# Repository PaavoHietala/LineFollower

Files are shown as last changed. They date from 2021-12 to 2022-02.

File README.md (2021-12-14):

# Line follower

Repository to build and program a line follower robot with arduino MEGA 2560.

The robot follows a line with two IR sensors and senses objects in front using ultrasound.

Course project for GCMG - Computational Graphics and Geometric Modelling of Técnico Lisboa.

## Arduino schematic

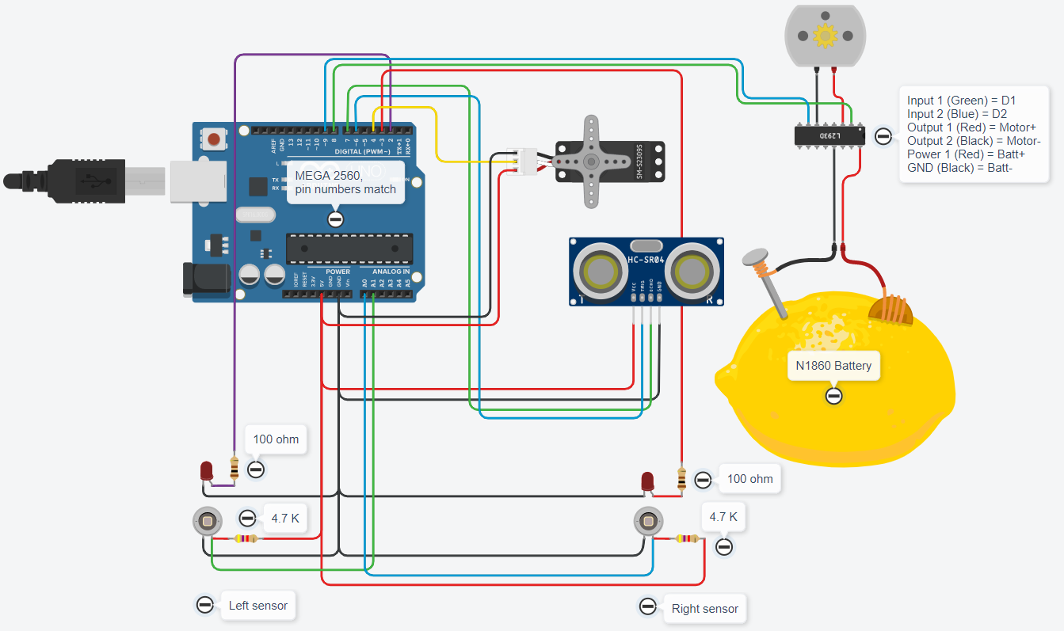
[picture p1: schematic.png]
Schematic Schematic, view PNG for increased resolution


Parts:
- 2 x TCRT5000 IR LED / photodiode combo
- Ultrasound sensor HC-SR04
- 2 x 100 ohm resistors
- 2 x 4.7 kohm resistors
- N18650 battery
- Small DC motor
- SG90 micro servo
- QUDONG BOSUN K-MEN motor controller (4-channel L9110)
- Whole lot of wire and soldering supplies

## Instructions

1. Build the electronics
2. Load the code to your arduino
3. Double check the pins in code and physical world

## Usage

The bot is autonomous. As long as it receives power, the program will run.

## Contributing

Unfortunately this project is my coursework, hence I am unable to receive external contributions. You can buy me a coffee if we meet though.

## License
[MIT](https://choosealicense.com/licenses/mit/)

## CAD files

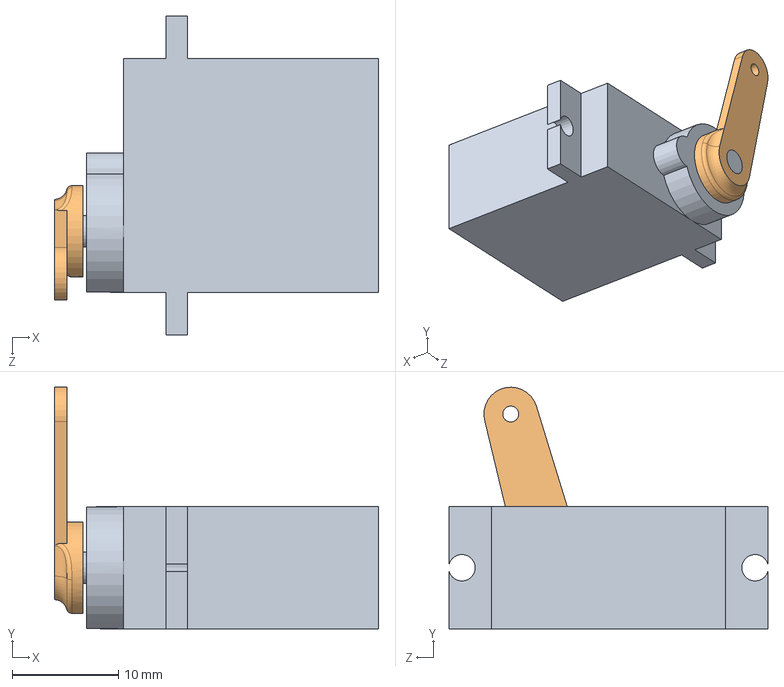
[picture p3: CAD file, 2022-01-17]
Solidworks/SG90 Servo Motor/servo assembly.SLDASM
30.5 x 22.7 x 30.0 mm
servo junk
servo junk 2

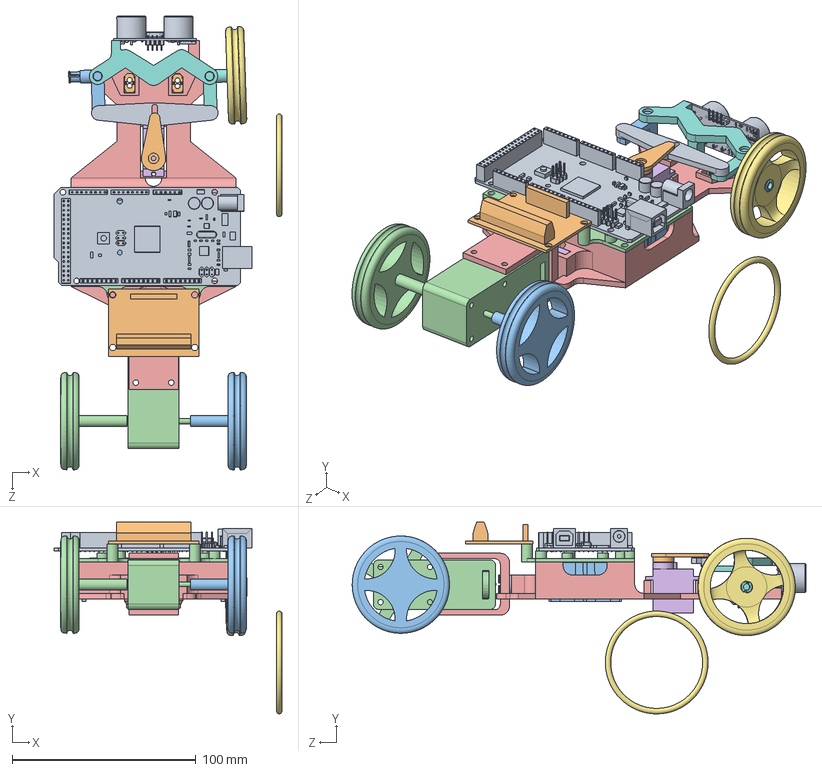
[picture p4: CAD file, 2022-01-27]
Solidworks/lineFollower.SLDASM
124.2 x 104.4 x 247.1 mm
Arduino Mega 2560
User Library-corpo TCRT 5000 x 2
Batt_Pack_Main
chassis_battery_cover
chassis_lower
servo junk
wheel
front_axle
steering_axle
servo_arm
front_axle_left_mirror
motor
motor_holder
motor_hinge
o-ring
front_fender
hc-sr04
motor_control_board
wheel_back_right
wheel_back_left

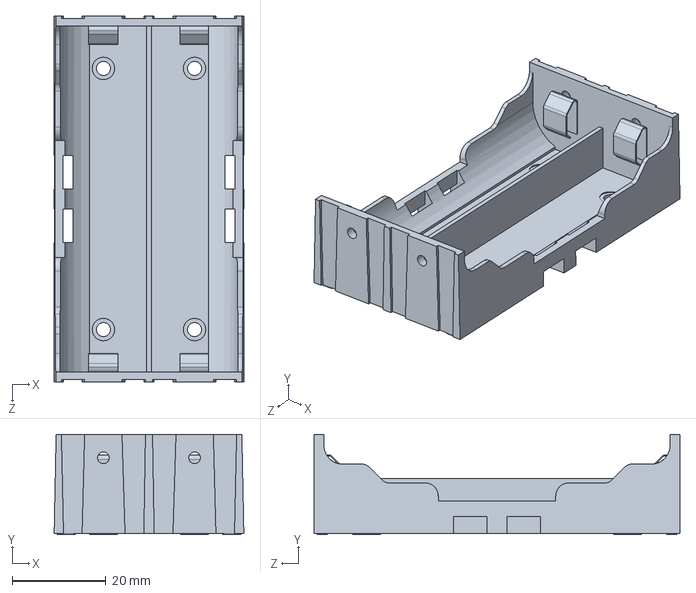
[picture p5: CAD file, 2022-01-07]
Solidworks/Batt_Pack_Main.SLDPRT
40.4 x 21.4 x 77.9 mm

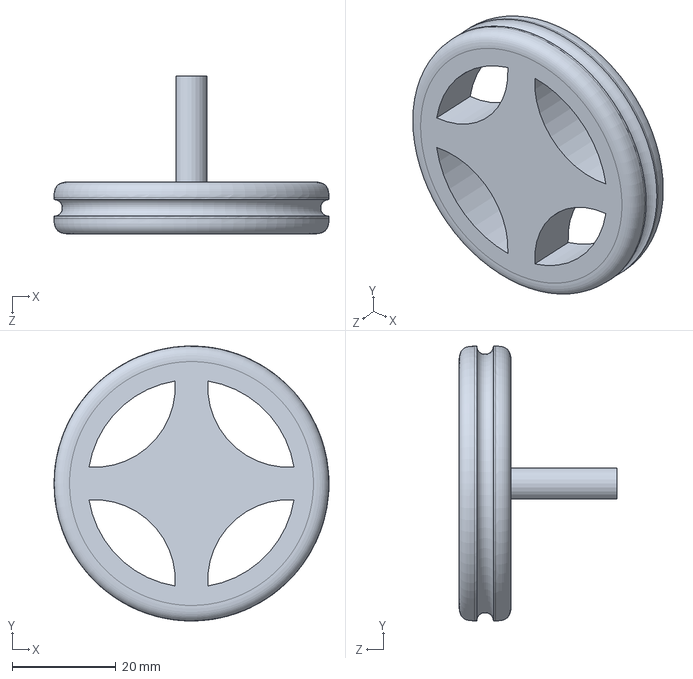
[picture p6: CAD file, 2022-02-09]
Solidworks/wheel_back_right.SLDPRT
53.0 x 53.0 x 30.4 mm

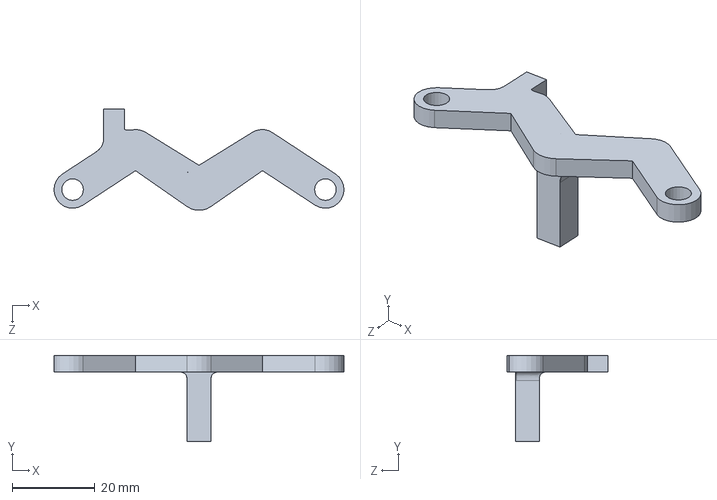
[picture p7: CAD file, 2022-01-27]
Solidworks/front_fender.SLDPRT
70.0 x 20.8 x 24.5 mm

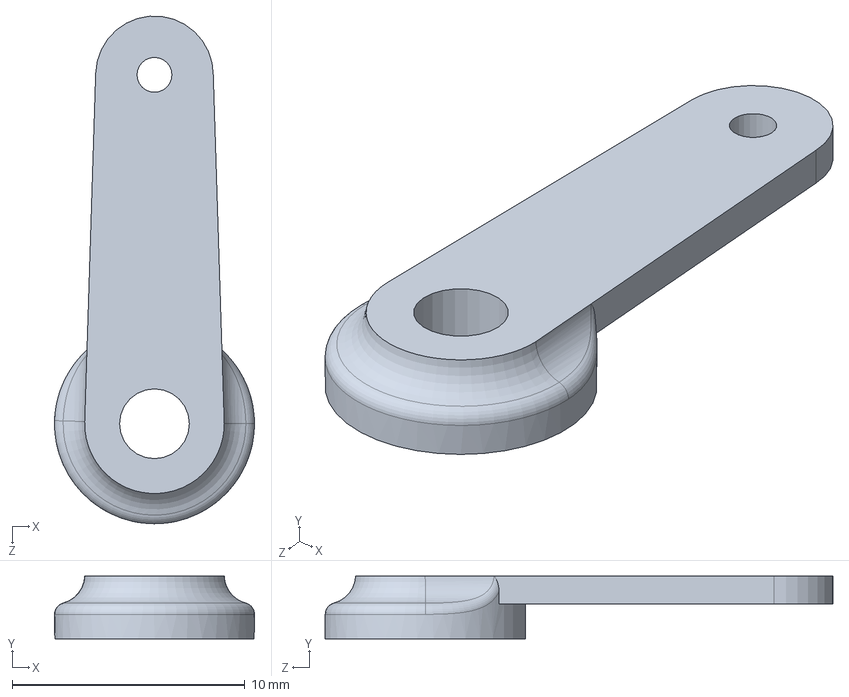
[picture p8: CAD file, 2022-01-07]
Solidworks/SG90 Servo Motor/servo junk 2.SLDPRT
8.60 x 2.70 x 21.8 mm

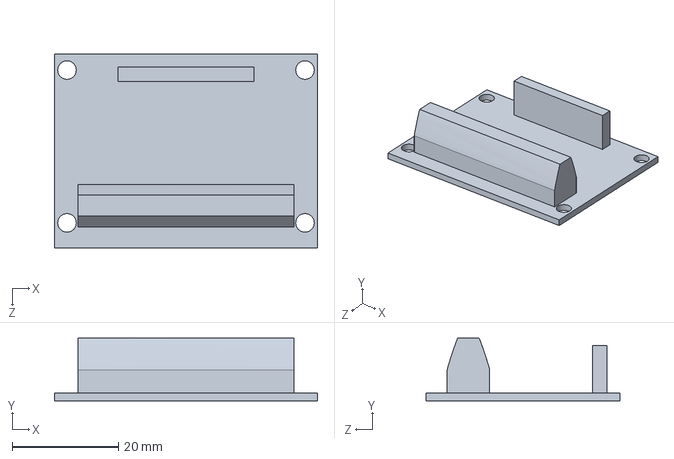
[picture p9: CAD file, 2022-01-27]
Solidworks/motor_control_board.SLDPRT
49.4 x 11.8 x 36.5 mm

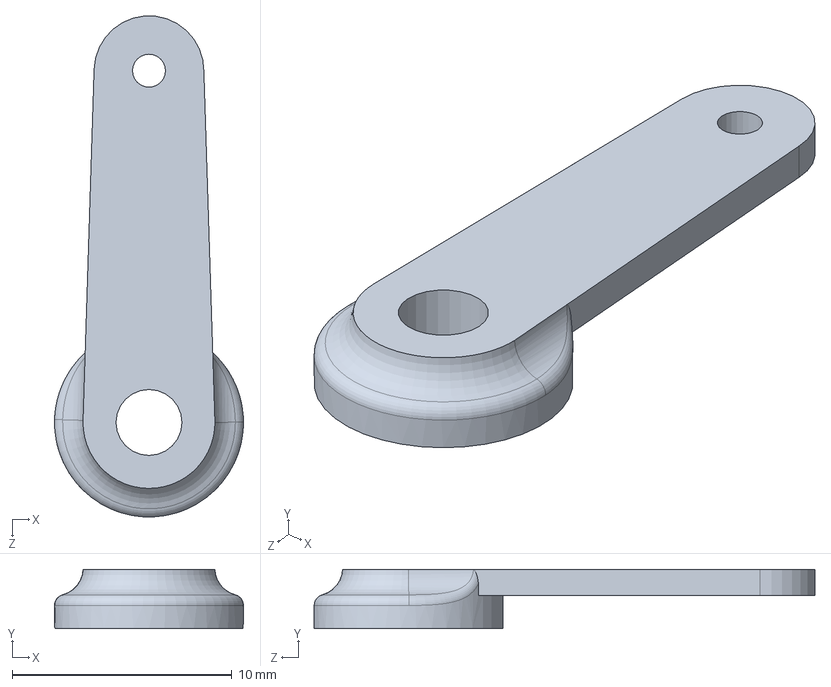
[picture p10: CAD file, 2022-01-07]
Solidworks/SG90 Servo Motor/servo junk 3.SLDPRT
8.60 x 2.70 x 22.8 mm

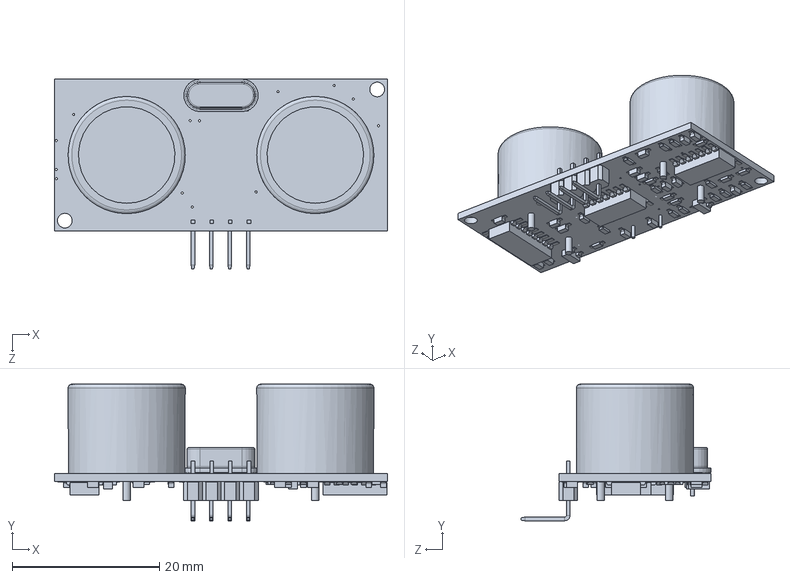
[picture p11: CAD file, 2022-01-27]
Solidworks/hc-sr04.SLDPRT
45.2 x 18.5 x 25.8 mm

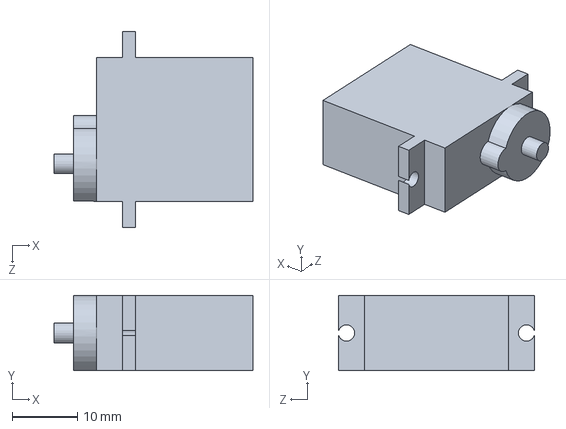
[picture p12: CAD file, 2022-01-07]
Solidworks/SG90 Servo Motor/servo junk.SLDPRT
30.5 x 11.5 x 30.0 mm

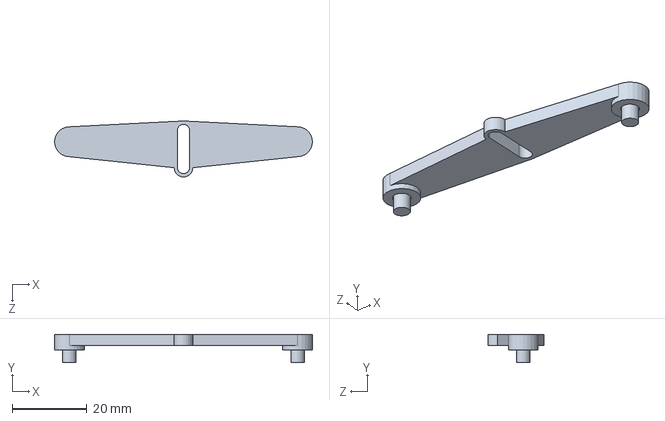
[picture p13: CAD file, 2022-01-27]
Solidworks/steering_axle.SLDPRT
69.0 x 7.50 x 15.0 mm

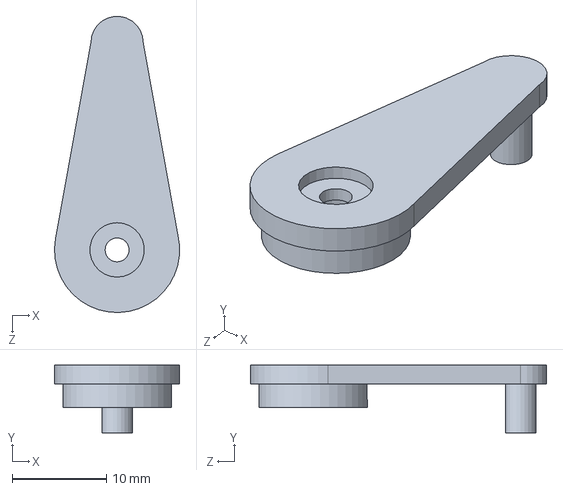
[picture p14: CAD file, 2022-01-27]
Solidworks/servo_arm.SLDPRT
13.3 x 7.20 x 31.4 mm

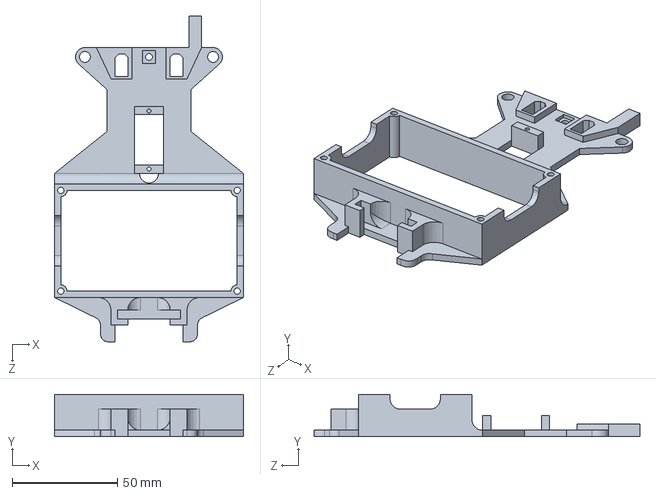
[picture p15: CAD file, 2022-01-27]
Solidworks/chassis_lower.SLDPRT
90.0 x 20.0 x 155.2 mm

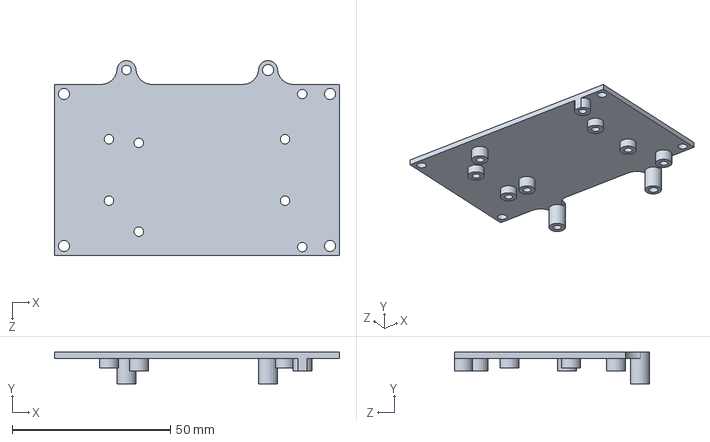
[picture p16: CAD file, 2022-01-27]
Solidworks/chassis_battery_cover.SLDPRT
90.0 x 10.0 x 61.6 mm

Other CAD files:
Solidworks/wheel_back_left.SLDPRT
Solidworks/motor_hinge.SLDPRT
Solidworks/motor_holder.SLDPRT
Solidworks/motor.SLDPRT
Solidworks/Arduino Mega 2560.SLDPRT
Solidworks/User Library-corpo TCRT 5000.sldprt
Solidworks/front_axle.SLDPRT
Solidworks/front_axle_left_mirror.SLDPRT
Solidworks/o-ring.SLDPRT
Solidworks/wheel.SLDPRT

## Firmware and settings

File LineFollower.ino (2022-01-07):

#define trigPin 7           // Trigger pin for distance sensor
#define echoPin 6           // Feedback pin from distance sensor
#define IRledPinLeft 2      // Left IR LED pin
#define IRledPinRight 3     // Right IR LED pin
#define IRpdLeft A1         // Left IR photodiode signal
#define IRpdRight A0        // Right IR photodiode signal
#define BlackThreshold -20  // Threshold for photodiode, on line if under this
#define debug 1             // Enable debugging output in serial monitor
#define motorD1 8           // Motor pin D1 (drive backwards)
#define motorD2 9           // Motor pin D2 (drive forwards)
#define ServoPin 4          // Servo pin for steering
#include <Servo.h>

Servo steering;             // Steering servo

void setup(){
    Serial.begin(9600);
    pinMode(trigPin, OUTPUT);
    pinMode(echoPin, INPUT);
    pinMode(IRledPinLeft, OUTPUT);
    pinMode(IRledPinRight, OUTPUT);
    pinMode(motorD1, OUTPUT);
    pinMode(motorD2, OUTPUT);
    steering.attach(ServoPin);
    steering.write(0);
    Serial.println("Setup completed");
}

void loop(){
    float distance;
    char left_IR;
    char right_IR;
    
    distance = check_distance();
    left_IR = check_IR('L');
    right_IR = check_IR('R');

    Serial.print(left_IR);
    Serial.print('\t');
    Serial.print(right_IR);
    Serial.print('\t');
    Serial.println(distance);

    driver(left_IR, right_IR, distance);
    
    delay(500);
}

int check_distance(){
    float duration;
    float distance;
    
    digitalWrite(trigPin, LOW); 
    delayMicroseconds(2);
    digitalWrite(trigPin, HIGH);
    delayMicroseconds(10);
    digitalWrite(trigPin, LOW);
    
    duration = pulseIn(echoPin, HIGH);
    distance = ((float)duration / 2.0) / 27.0;
    
    return distance;
}

char check_IR(char side){
    int sigNoise, sig, noise, ledPin;
    uint8_t pdPin;

    if (side == 'R'){
        ledPin = IRledPinRight;
        pdPin = IRpdRight;
        if(debug==1){Serial.print("Right: ");}
    }
    else{
        ledPin = IRledPinLeft;
        pdPin = IRpdLeft;
        if(debug==1){Serial.print("Left: ");}
    }
    
    digitalWrite(ledPin, HIGH);
    delayMicroseconds(100);
    sigNoise = analogRead(pdPin); // Read noisy photodiode signal (led on)
    digitalWrite(ledPin, LOW);
    delayMicroseconds(100);
    noise = analogRead(pdPin); // Read only noise from photodiode (led off)
    sig = sigNoise - noise;
    
    if(debug==1){Serial.println(sig);}

    if (sig >= BlackThreshold){
        return 'W';
    }
    else{
        return 'B';
    }
}

void driver(char left_IR, char right_IR, float distance){
    if ((left_IR == 'B' && right_IR == 'B') || distance <= 5){
        Serial.println("stop");
        motor_ctrl("stop");
    }
    else if (left_IR == 'B' && right_IR == 'W'){
        Serial.println("Turning left");
        steering.write(30);
        motor_ctrl("fwd");
    }
    else if (left_IR == 'W' && right_IR == 'B'){
        Serial.println("Turning right");
        steering.write(150);
        motor_ctrl("fwd");
    }
    else{
        Serial.println("Full steam ahead");
        steering.write(90);
        motor_ctrl("fwd");
    }
}

void motor_ctrl(char* task){
    if (task == "fwd"){
        Serial.println("Driving motor forward");
        analogWrite(motorD1, LOW);
        analogWrite(motorD2, 255);
    }
    else if (task == "stop"){
        Serial.println("Stopping motor");
        analogWrite(motorD1, LOW);
        analogWrite(motorD2, LOW);
    }
    else if (task == "rev"){
        Serial.println("Driving motor backwards");
        analogWrite(motorD1, 255);
        analogWrite(motorD2, LOW);
    }
}

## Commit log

2021-12-11 Initial commit, sensors working with driver dummy
2021-12-14 Added support for drive motor
2021-12-14 Steering servo working, updated readme with schema
2021-12-14 Updated schematic
2022-01-07 Started solidworks modeling
    [Arduino Mega 2560.SLDPRT, Batt_Pack_Main.SLDPRT, Connecteur HC-SR04.SLDPRT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]
2022-01-12 Refined chassis, redesigned battery cover
    [chassis_battery_cover.SLDPRT, chassis_lower.SLDPRT, lineFollower.SLDASM]
2022-01-17 Steering mechanism works, modified servo placing and frame
    [chassis_lower.SLDPRT, front_axle.SLDPRT, front_axle_left_mirror.SLDPRT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]
2022-01-25 Added motor with holder and front fender, redone wheel
    [chassis_lower.SLDPRT, front_fender.SLDPRT, lineFollower.SLDASM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]
2022-01-27 Modified chassis
    [chassis_lower.SLDPRT]
2022-01-27 Added battery cable holes to chassis
    [chassis_lower.SLDPRT]
2022-01-27 Redesigned parts according to printed model. Added rear wheels and motor controller.
    [Connecteur HC-SR04.SLDPRT, HC-SR04.SLDASM, MircoGrand de HC-SR04.SLDPRT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]
2022-02-09 testing wheel axle diameter
    [wheel_back_right.SLDPRT]
